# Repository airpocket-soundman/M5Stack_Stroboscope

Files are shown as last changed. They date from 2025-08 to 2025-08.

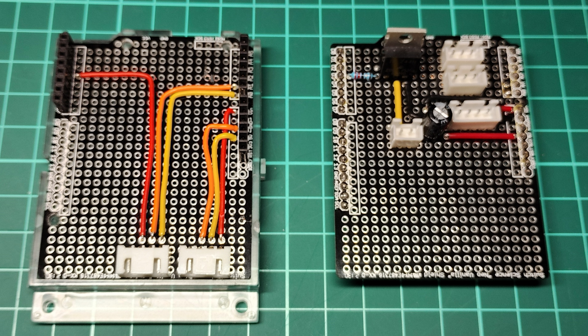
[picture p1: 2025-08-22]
img/arduino_convert_board.png

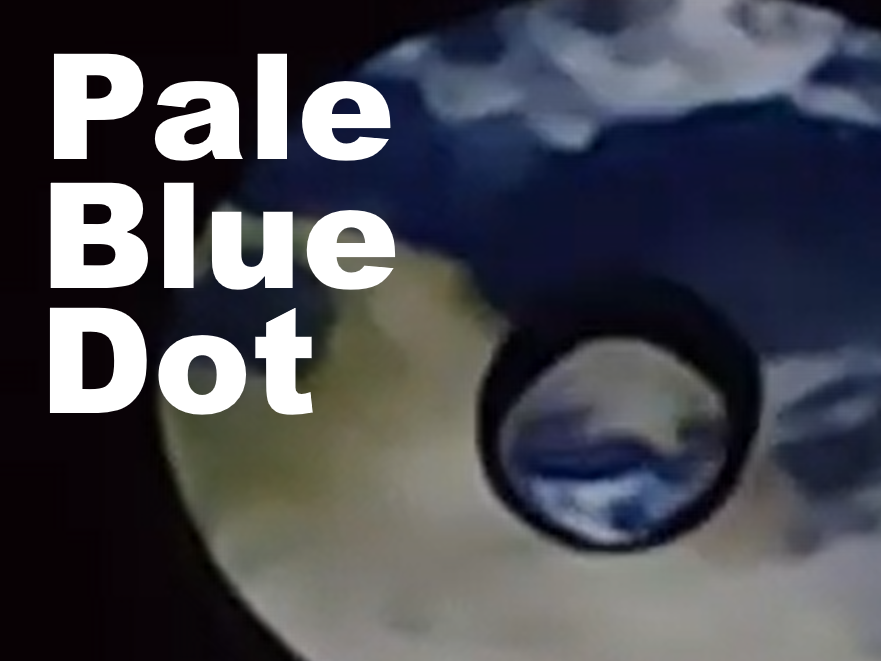
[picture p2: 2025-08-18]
img/cover.png

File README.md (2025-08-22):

# M5Stack_Stroboscope
stroboscope

## このプロジェクトの意義

この作品は科学教育及び科学法則を利用したアートプロジェクトです。
ストロボスコープによる周期運動の観察と、無重力を感じさせる空中の水滴への画像投影を実現しています。広大な宇宙に浮かぶ小さな地球の美しくも儚い姿を表現しました。

## ストロボスコープとは

ストロボスコープとは、周期的に強い光を発することで、高速で動く物体の動きを観察できる装置です。 周期運動している物体に、その運動周期に同期した光を照射すると、物体の動きが停止しているように見える現象が生じます。この現象はストロボスコピック効果（またはストロボ効果）と呼ばれ、光の周期をわずかにずらすことで、スローモーションや逆再生のような視覚効果を得ることもできます。 市販の装置も多く販売されており、高速回転するモータやファン、スピーカなどの振動体の観測・測定に利用されています。一般的な市販品は、数マイクロ秒から数ミリ秒の発光を、1秒間に最大1000〜2000回程度行える仕様が多い様です。 人間の目が短時間の発光を認識するには強い光が必要なため、高サイクルでの観察にはより高輝度な照明が求められます。そのため、ストロボスコープは短時間で強い光を発光できるように設計されています。 このプロジェクトではM5Stackを使用してストロボスコープを制作し、M5Stackのディスプレイに表示したアニメーションを水滴の中に投影します。

## ストロボスコープとしての機能
ストロボスコープとして使用する為に、白色LED９個を束ねたフラッシュライトモジュールを制作しています。これにより、任意のオブジェクトを照明で照らして観察できます。
今回は、水滴を滴下する装置を作成し、水滴を観察しています。
また、MSStackのディスプレイにアニメーションを表示しつつ、LED照明の代わりに、ディスプレイのバックライトを点滅させることで水滴にディスプレイのイメージを投影できます。
コントローラに配置した二つのポテンショメータでフラッシュライトの点灯周期及び点灯時間を調節できます。点灯周期を変更するとこで、水滴が停止したりスローモーションで動いたりといった視覚効果を得られます。

## 水滴滴下装置

水滴をストロボスコープで観察する為に滴下装置を制作しました。上部タンクに水をため、下部のノズルから水圧により周期的な水滴の滴下を行います。ノズルはシリコーンゴムチューブで制作し、途中に配置したローラクランプで滴下速度を調節できます。
滴下装置の筐体は３Dプリンタ部品で制作しました。

## 制御回路
　
この装置は当初ストロボスコープの制御をArduino UNOで行い、アニメーション表示をM5StackCore2で行っていました。写真右のArduino Uno用のシールド基板を制作しMOSFETでのスイッチング回路や滴下タイミング制御用のポテンショメータと接続していました。M5StackCore2であれば、点灯制御とアニメーション制御を1台で賄えるため、写真左の接続用ボードを追加作成し、このボードを経由して制御基板へ接続しています。
M5StackCore2のG35,G36のADCでポテンショメータを読み取り、G26でストロボスコープ点灯用タイミング信号を出力しています。

M5Stackからの制御信号の出力にはBASE26を使用しています。BASE26にはDC-DCコンバータが搭載されているため、電源としてDC12Vを入力してコントローラとポンプの駆動に利用しています。ポンプの駆動には12Vのまま利世しています。

## M5StackCore2の改造
　
M5StackCore2のディスプレイのバックライトを制御するため、バックライトのFPCから電源回路を取り出しています。この回路をストロボスコープ用の回路に接続することで、ストロボスコープ同様の点灯制御ができます。

## アニメーションの表示

M5Stackのディスプレイに表示するアニメーションはマイクロSDに保存しています。保存形式はRGB565（16bit）BMPにします。画像サイズはディスプレイに合わせて320×240pixelにするのが良いでしょう。今回は地球の表示であったため、読み込み時間削減のため、240×240pixelの画像を使用しています。

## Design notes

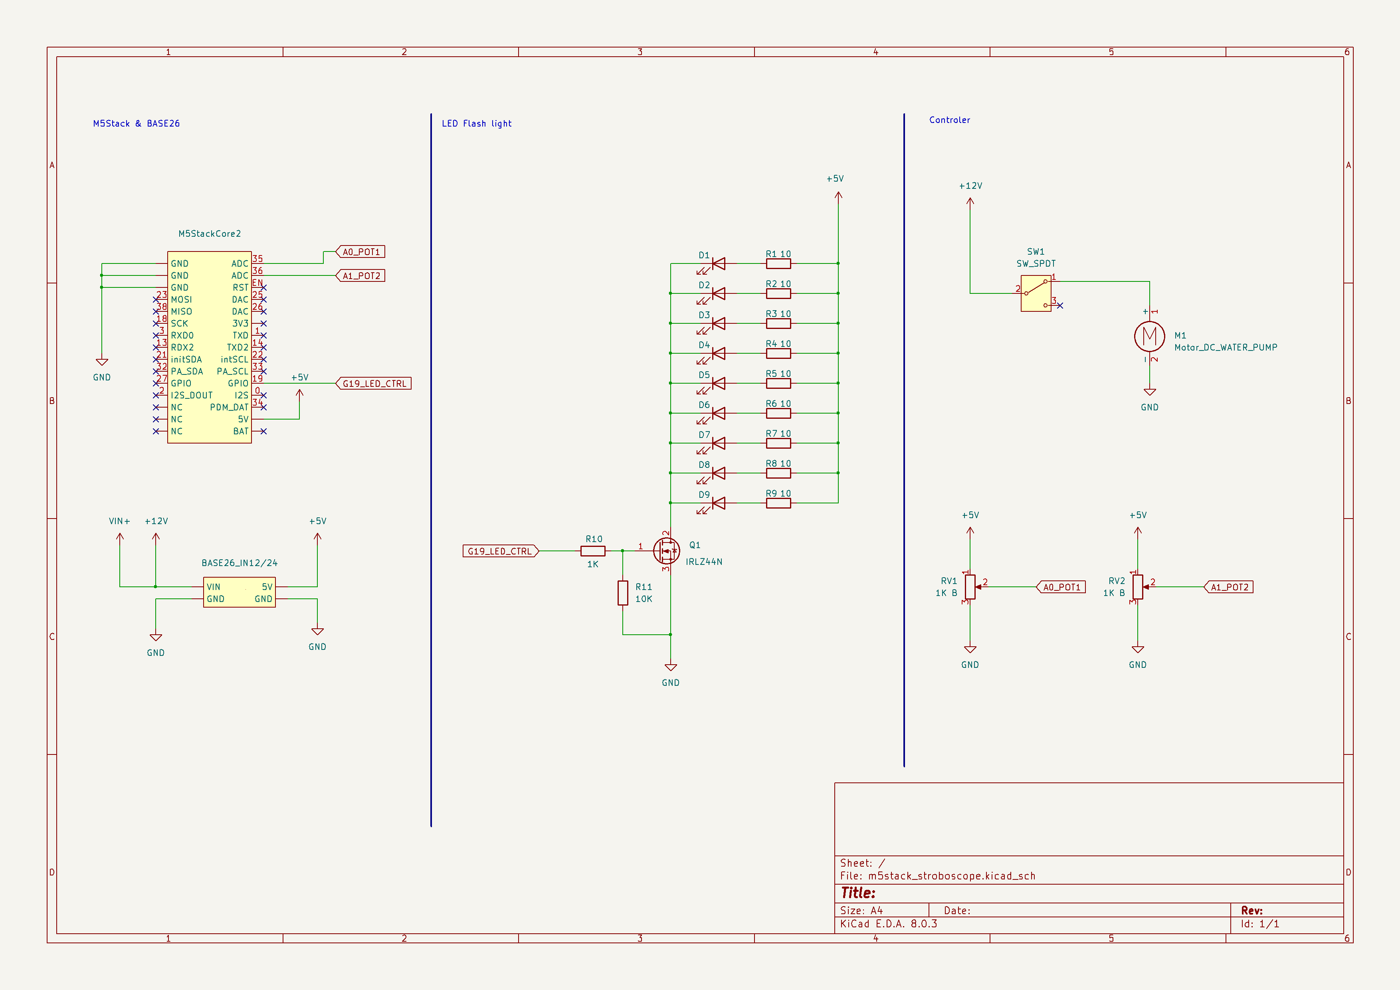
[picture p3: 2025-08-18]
img/schematic.png

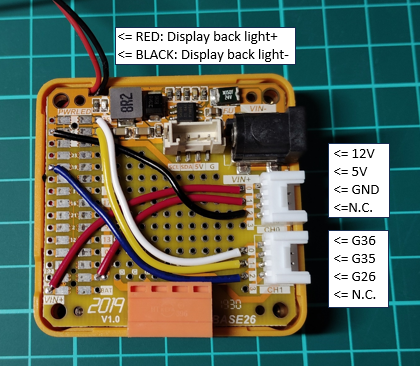
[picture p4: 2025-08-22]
img/m5stack_base26_board.png

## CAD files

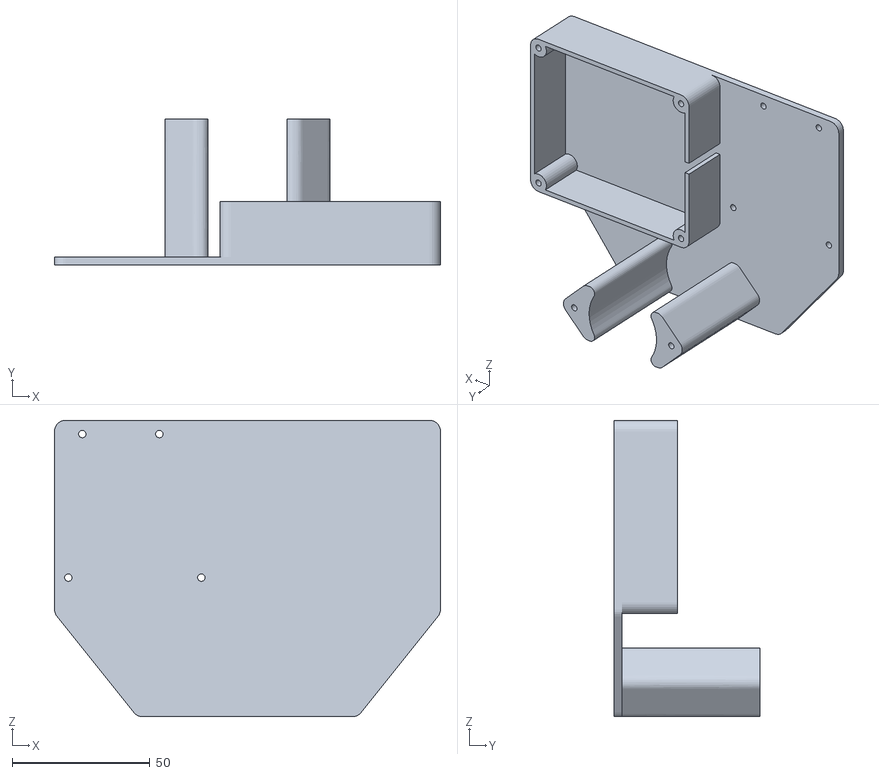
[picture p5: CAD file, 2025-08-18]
stls/switch box base v2.stl
140.0 x 53.0 x 107.5

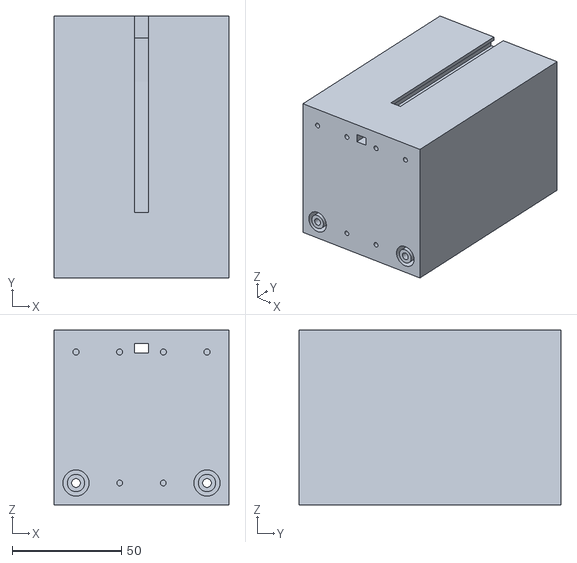
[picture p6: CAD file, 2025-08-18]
stls/water tank v8.stl
80.0 x 120.0 x 80.0

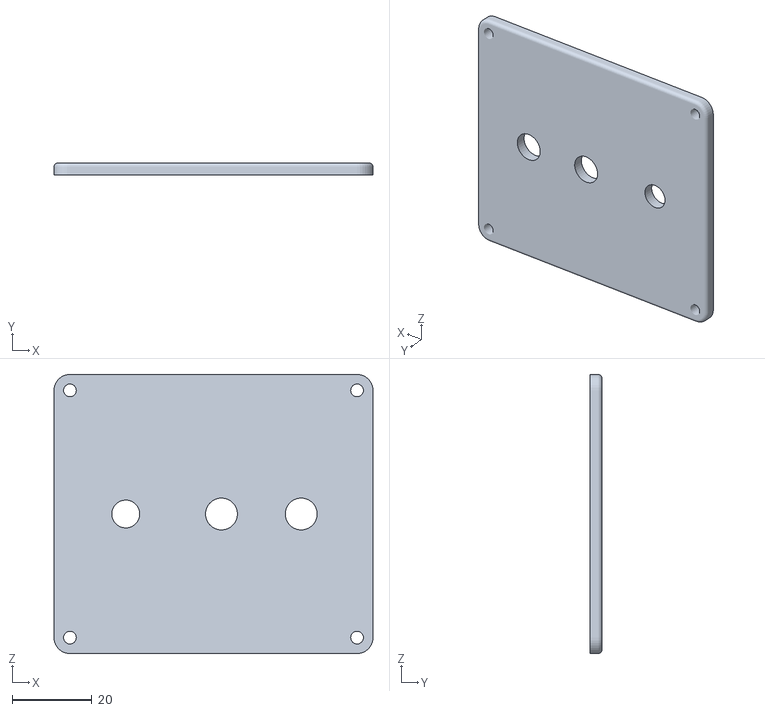
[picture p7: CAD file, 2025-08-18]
stls/switch box top v2.stl
80.0 x 3.00 x 70.0

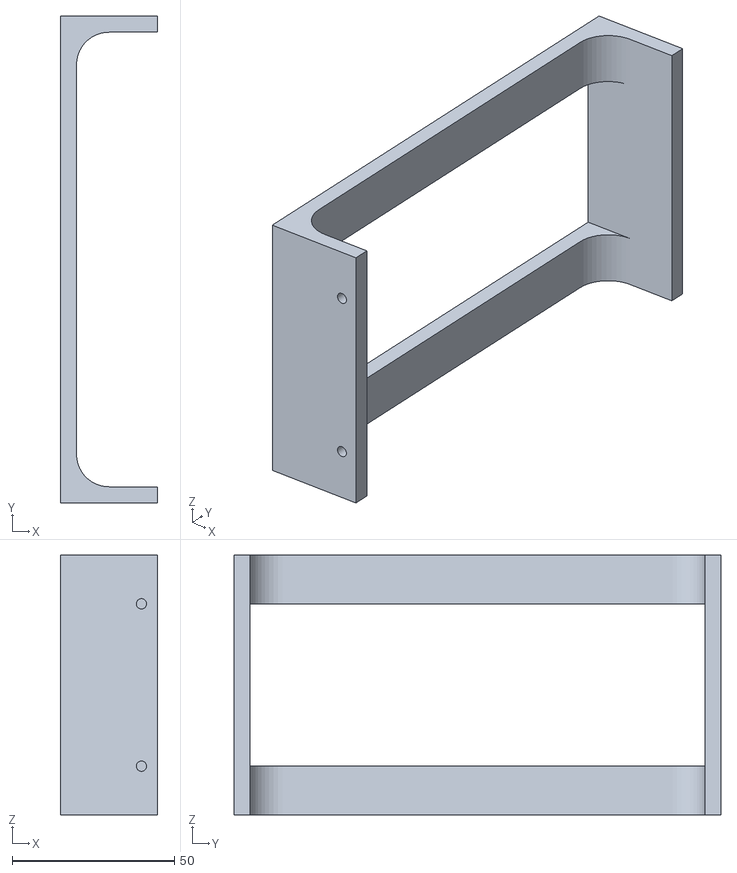
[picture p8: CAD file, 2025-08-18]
stls/foot v2.stl
30.0 x 150.0 x 80.0

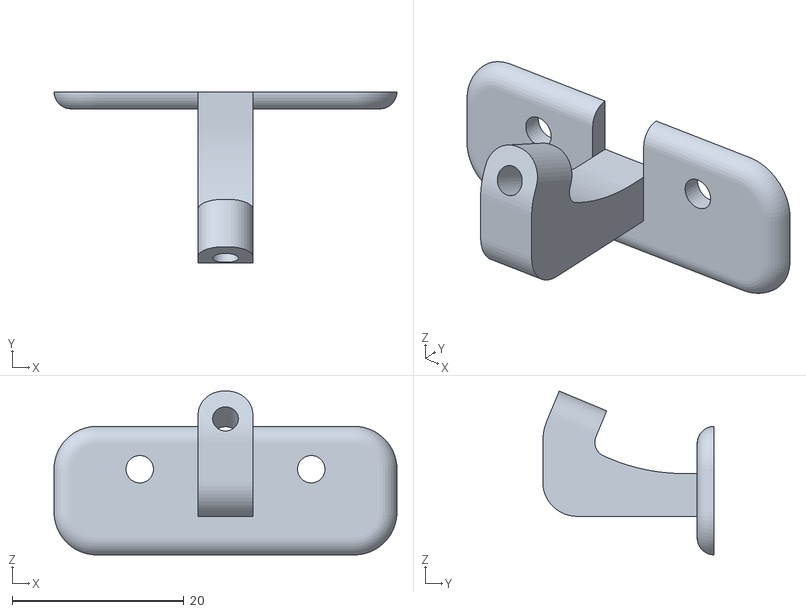
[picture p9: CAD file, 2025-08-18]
stls/tube holder v3.stl
40.0 x 20.0 x 19.1

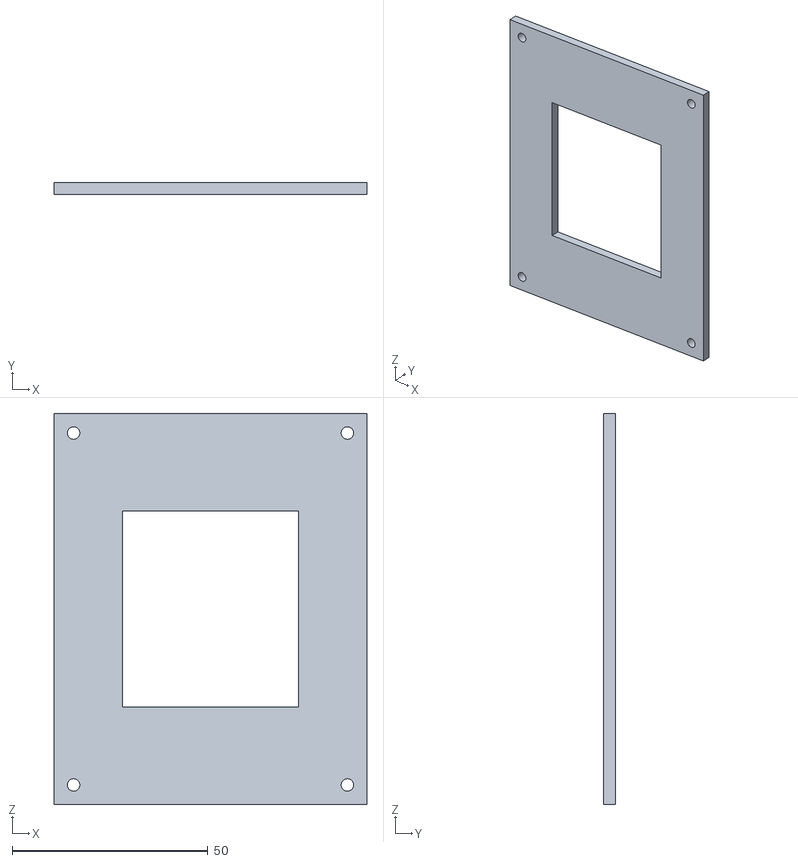
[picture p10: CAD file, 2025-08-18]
stls/mastack cover v2.stl
80.0 x 3.00 x 100.0

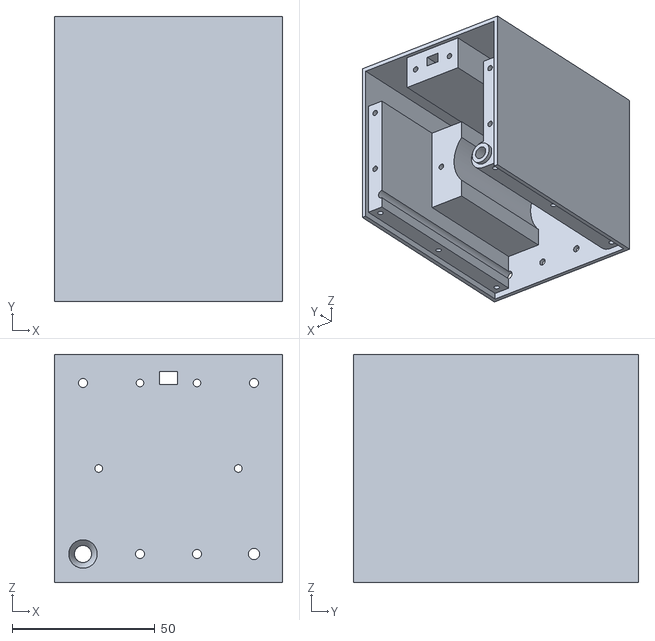
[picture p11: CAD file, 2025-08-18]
stls/tank_base.stl
80.0 x 100.0 x 80.0

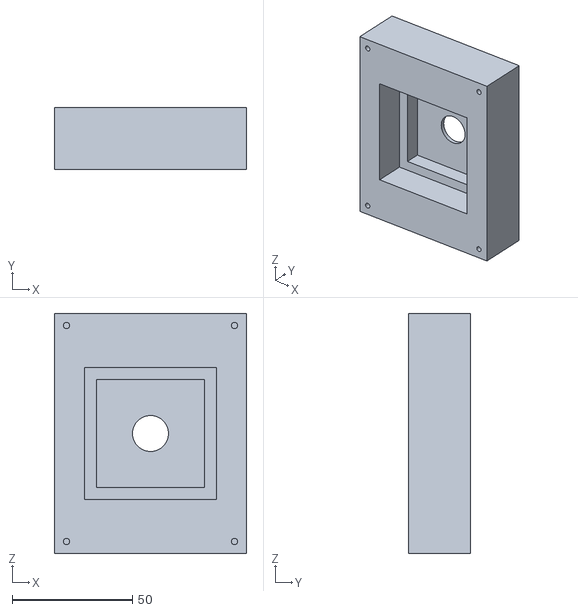
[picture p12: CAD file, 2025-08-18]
stls/m5stack case v3.stl
80.0 x 26.0 x 100.0

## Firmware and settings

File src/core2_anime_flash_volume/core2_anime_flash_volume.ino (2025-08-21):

#include <M5Unified.h>
#include <SD.h>
#include <esp_timer.h>

// ===== 再生設定 =====
static int  FRAME_COUNT      = 199;   // 再生枚数（初期199）
static int  FRAME_DELAY_MS   = 0;     // フレーム間待ち(0=できるだけ速く)
static const int START_Y     = 0;     // 縦位置は固定
static const int LCD_W       = 320;   // Core2: 320x240

// ===== ストロボ（フレームとは非同期・独立） =====
// 初期値（参照コード準拠）
static volatile uint32_t g_on_us  = 100;     // 点灯時間(µs)
static volatile uint32_t g_off_us = 30000;   // 消灯時間(µs) → 周期 = on + off

// つまみ（Core2のADC入力）
static const int ADC_OFF_PIN = 36;  // サイクル(=off)用（入力専用ピン）
static const int ADC_ON_PIN  = 35;  // 点灯(on)用（入力専用ピン)

// マッピング範囲（必要に応じて調整）
static const uint32_t OFF_MIN_US = 1000;     // 1ms
static const uint32_t OFF_MAX_US = 100000;   // 100ms
static const uint32_t ON_MIN_US  = 10;       // 10µs
static const uint32_t ON_MAX_US  = 10000;    // 10ms

static const float ADC_EMA_ALPHA = 0.20f;    // 平滑（0<alpha<=1）

// ストロボ出力（Core2でSDと競合しないピン）
static const int STROBE_PIN = 26;

// タイマ
static esp_timer_handle_t g_periodic_timer     = nullptr;
static esp_timer_handle_t g_one_shot_off_timer = nullptr;

// ===== 画像用：PSRAMバッファ使い回し（毎回malloc/freeしない） =====
static uint8_t* g_buf = nullptr;
static size_t   g_cap = 0;

// ===== ユーティリティ =====
static inline uint32_t umap(uint32_t x, uint32_t in_min, uint32_t in_max,
                            uint32_t out_min, uint32_t out_max) {
  if (x <= in_min) return out_min;
  if (x >= in_max) return out_max;
  uint64_t num = (uint64_t)(x - in_min) * (out_max - out_min);
  return out_min + (uint32_t)(num / (in_max - in_min));
}

// BMP幅をファイルヘッダから取得（リトルエンディアン / 18バイト目から4バイト）
// ※いまは描画座標固定なので未使用だが、将来の可変幅対応のため残置
static int getBmpWidth(File &f) {
  uint8_t hdr[26];
  if (!f.seek(0)) return -1;
  size_t r = f.read(hdr, sizeof(hdr));
  if (r < 22) return -1;
  int32_t w = (int32_t)( (uint32_t)hdr[18]
                       | ((uint32_t)hdr[19] << 8)
                       | ((uint32_t)hdr[20] << 16)
                       | ((uint32_t)hdr[21] << 24) );
  if (w < 0) w = -w;  // トップダウンBMPは絶対値扱い
  f.seek(0);
  return w;
}

// ===== ストロボ割り込み =====
static void IRAM_ATTR one_shot_off_cb(void*) {
  gpio_set_level((gpio_num_t)STROBE_PIN, 0);
}

static void IRAM_ATTR periodic_cb(void*) {
  gpio_set_level((gpio_num_t)STROBE_PIN, 1);
  uint32_t on_us = g_on_us;
  if (g_one_shot_off_timer) {
    esp_timer_stop(g_one_shot_off_timer);
    esp_timer_start_once(g_one_shot_off_timer, on_us);
  }
}

static void update_periodic_timer(uint32_t on_us, uint32_t off_us) {
  // 範囲ガード
  if (on_us  < ON_MIN_US)  on_us  = ON_MIN_US;
  if (on_us  > ON_MAX_US)  on_us  = ON_MAX_US;
  if (off_us < OFF_MIN_US) off_us = OFF_MIN_US;
  if (off_us > OFF_MAX_US) off_us = OFF_MAX_US;

  g_on_us  = on_us;
  g_off_us = off_us;

  uint32_t period_us = on_us + off_us;
  if (g_periodic_timer) {
    esp_timer_stop(g_periodic_timer);
    esp_timer_start_periodic(g_periodic_timer, period_us); // µs周期
  }

  // 基本ログ（ここは常時出す）
  Serial.printf("Strobe set: on=%u us, off=%u us (period=%u us)\n", on_us, off_us, period_us);
}

// ===== セットアップ =====
void setup() {
  Serial.begin(115200);
  delay(200);
  Serial.println("=== Setup ===");

  auto cfg = M5.config();
  M5.begin(cfg);
  M5.Display.setRotation(0);
  M5.Display.fillScreen(TFT_BLACK);

  // SD（Core2のTFスロット）
  if (!SD.begin(GPIO_NUM_4)) {
    Serial.println("SD init failed");
    while (true) delay(1000);
  }
  Serial.println("SD OK");

  // ストロボ出力
  pinMode(STROBE_PIN, OUTPUT);
  digitalWrite(STROBE_PIN, LOW);

  // ADC
  analogReadResolution(12);

  // タイマ作成
  esp_timer_create_args_t periodic_args = {};
  periodic_args.callback = &periodic_cb;
  periodic_args.name     = "strobe_periodic";
  ESP_ERROR_CHECK(esp_timer_create(&periodic_args, &g_periodic_timer));

  esp_timer_create_args_t off_args = {};
  off_args.callback = &one_shot_off_cb;
  off_args.name     = "strobe_off";
  ESP_ERROR_CHECK(esp_timer_create(&off_args, &g_one_shot_off_timer));

  // 初期ストロボ設定（参照コード準拠）
  update_periodic_timer(g_on_us, g_off_us);

  Serial.println("=== Ready ===");
}

// ===== メインループ =====
void loop() {
  // 1) アナログ入力から on/off を更新（独立保持）
  static float ema_off = 2000.0f, ema_on = 500.0f;
  int raw_off = analogRead(ADC_OFF_PIN);   // 0..4095
  int raw_on  = analogRead(ADC_ON_PIN);    // 0..4095
  ema_off = (1.0f - ADC_EMA_ALPHA) * ema_off + ADC_EMA_ALPHA * raw_off;
  ema_on  = (1.0f - ADC_EMA_ALPHA) * ema_on  + ADC_EMA_ALPHA * raw_on;

  uint32_t new_off_us = umap((uint32_t)ema_off, 0, 4095, OFF_MIN_US, OFF_MAX_US);
  uint32_t new_on_us  = umap((uint32_t)ema_on,  0, 4095, ON_MIN_US,  ON_MAX_US);

  // 前回値との差を見て更新するか判断（しきい値は調整可）
  static uint32_t last_off_us = 0, last_on_us = 0;
  if (abs((int)new_off_us - (int)last_off_us) > 50 ||   // 50µs以上変化
      abs((int)new_on_us  - (int)last_on_us)  > 10) {   // 10µs以上変化

    // まずタイマ更新（µs単位で周期変更）
    update_periodic_timer(new_on_us, new_off_us);

    // デバッグ出力：アナログ→EMA→マッピング→最終設定
    uint32_t period_us = new_on_us + new_off_us;
    float    freq_hz   = (period_us > 0) ? (1000000.0f / (float)period_us) : 0.0f;
    float    duty_pct  = (period_us > 0) ? (100.0f * (float)new_on_us / (float)period_us) : 0.0f;

    Serial.printf(
      "[STROBE] raw(off,on)=(%4d,%4d)  EMA(off,on)=(%6.1f,%6.1f)  "
      "on=%u us  off=%u us  period=%u us  freq=%.2f Hz  duty=%.2f%%  (GPIO=%d)\n",
      raw_off, raw_on, ema_off, ema_on,
      new_on_us, new_off_us, period_us, freq_hz, duty_pct, STROBE_PIN
    );

    last_off_us = new_off_us;
    last_on_us  = new_on_us;
  }

  // 2) 画像を1コマだけ描画（非ブロッキング）
  static int frame_i = 1;  // 現在のフレーム番号を保持

  char filename[32];
  sprintf(filename, "/%04d_240.bmp", frame_i);

  File f = SD.open(filename, FILE_READ);
  if (f) {
    size_t len = f.size();
    if (len > g_cap) {
      if (g_buf) { free(g_buf); g_buf = nullptr; g_cap = 0; }
      g_buf = (uint8_t*)ps_malloc(len);
      if (!g_buf) {
        f.close();
        Serial.println("ps_malloc failed");
        delay(1);
        return;
      }
      g_cap = len;
    }

    f.read(g_buf, len);
    f.close();

    M5.Display.drawBmp(g_buf, len, 0, 40);  // あなたの指定どおり座標は固定
  }

  // 次のフレームへ進める（ループ再開）
  frame_i++;
  if (frame_i > FRAME_COUNT) frame_i = 1;

  // フレーム間ディレイ
  if (FRAME_DELAY_MS > 0) delay(FRAME_DELAY_MS);
  else delay(1);  // 最低限の呼吸
}

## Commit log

2025-08-20 MD追記など
2025-08-21 ソース修正。
2025-08-22 MD修正
    [Book1.xlsx]
